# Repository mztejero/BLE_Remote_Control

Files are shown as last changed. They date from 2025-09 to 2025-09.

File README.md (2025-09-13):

<p align="center">
Plot
</p>

This remote control is designed to send incremental inputs over Bluetooth Low Energy. In this specific application, steering and throttle values are set with the rotary encoders and the x and y values of the joysticks are set in a range of -100 to 100. All of these values are sent as a package over BLE.
Running the ```ble_test.py``` shows the unpacked messages being received as shown below. 

<p align="center">
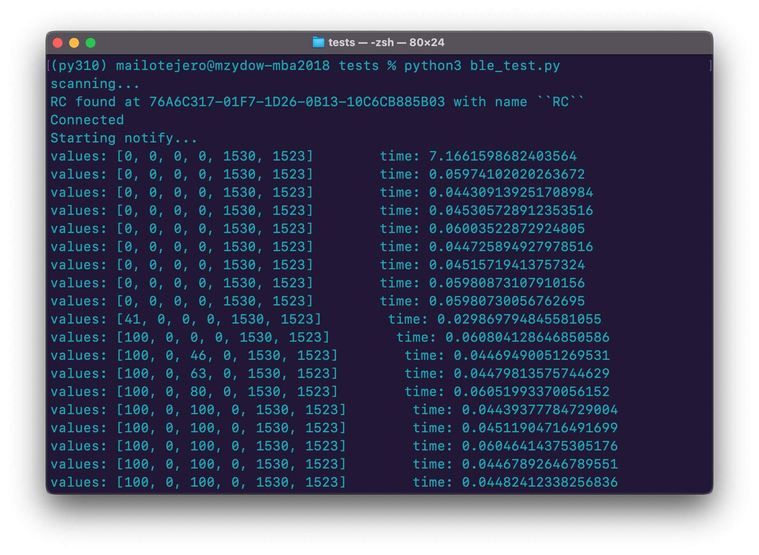
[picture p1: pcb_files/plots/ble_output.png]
Plot

</p>

# ESP-IDF
The file architecture is split into each of the remote's functions with each ```.c``` file also havng a complementary ```.h``` file allowing variable and function sharng across the project.
The files can be found in ```BLE_Remote_Control/main```:
```
config.c
joystick.c
bluetooth.c
encoder.c
lcd.c
buttons.c
main.c
```
```config.c```      Sets up and names the GPIO's used on the ESP32. <br>
```joystick.c```    Reads ADC values from the joystick potentiometers, estimates offsets, and converts the values into a range from -100 to 100. <br>
```bluetooth.c```  Uses NimBLE to run the ESP32 as a server by advertising through a GAP and publishing data packets through a GATT at 50 Hz. <br>
```encoder.c```     Sets up interrupts on quadrature encoders A and B terminals with tasks for counting which are added to queues. <br>
```lcd.c ```        Handles communication with LCD 16x02 via I<sup>2</sup>C. Transfers data through 4-bit nibbles and prints values on the screen (as shown in first picture). <br>
```buttons.c```     Placeholder script for reading switch values from encoders and joysticks. These are not currently used in this project. <br>
```main.c```        Main script for initializing and running the project on ESP32.

# Schematics
<p align="center">
<img src="pcb_files/plots/RC_schematics.png" alt="Plot" width="700"/>
</p>

This PCB is designed using the following components:

## SMD Components
ESP32-WROOM-32E -- Microcontroller used to run firmware, read sensors, write to actuators, and handle BLE communication. <br>
CP2102A USB-to-UART -- Interface for uploading code to the ESP32-WROOM-32E. The NPN transistors circuitry automatically put the ESP32 into bootloader mode when a new upload happens.<br>
<br>
PCF8574A I2C I/O for LCD communication -- Uses SCL and SDA to convert I<sup>2</sup>C data into bits to send to the LCD 16x02. Circuitry implements n-type MOSFETs for level shifting between 5V and 3V3 <br>
AMS1117-3.3 -- Converts 5V into 3.3V for components requiring 3V3<br>

## Hand-Soldered Components
Rotary Encoders -- Quadrature encoders with A and B terminals connected to GPIOs with pull-ups. Interrupts on these pull-ups are triggered upon rotation. <br>
Joysticks -- Use 2 potentiometers, one for x direction and one for y direction. These values are read through the ESP32's ADC. <br>
LCD 16x02 -- Displays characters on a 16×2 grid from data bits. <br>
Potentiometer -- Adjusts LCD lighting. <br>

# Final PCB Design
<p align="center">
<img src="pcb_files/plots/RC_pcb.png" alt="Plot" width="700"/>
</p>

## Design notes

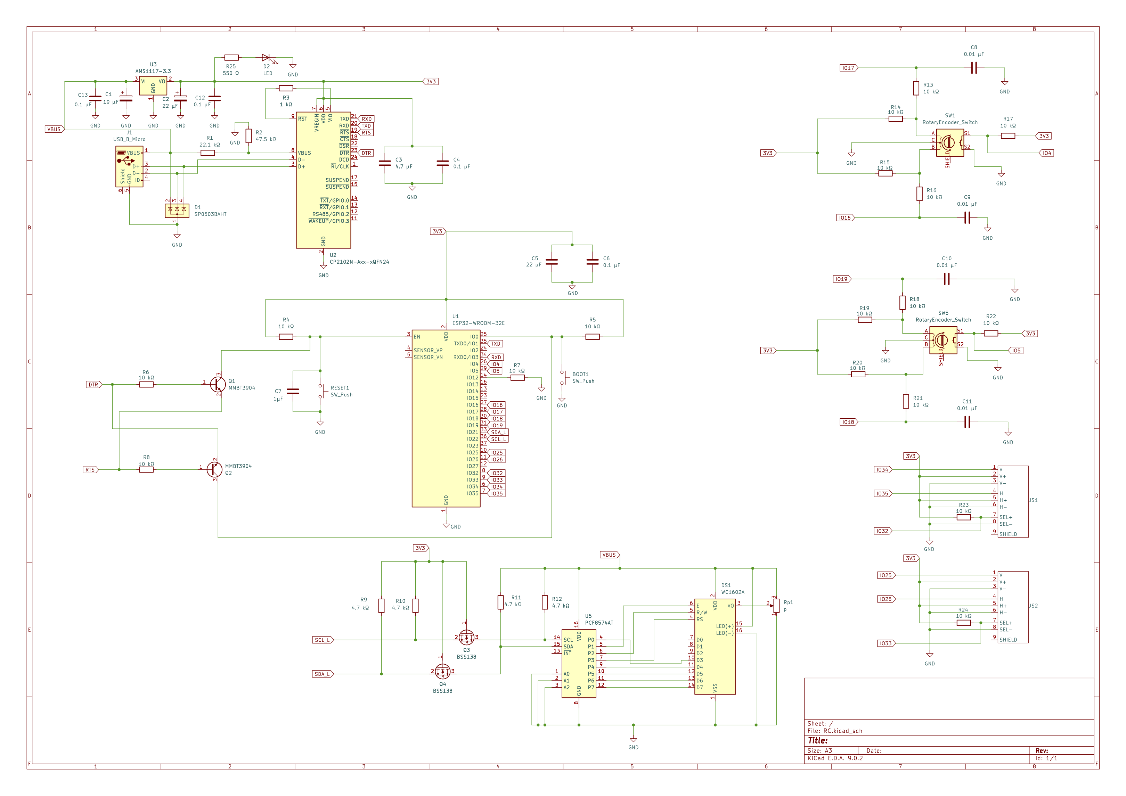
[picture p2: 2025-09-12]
pcb_files/plots/RC_schematics.png

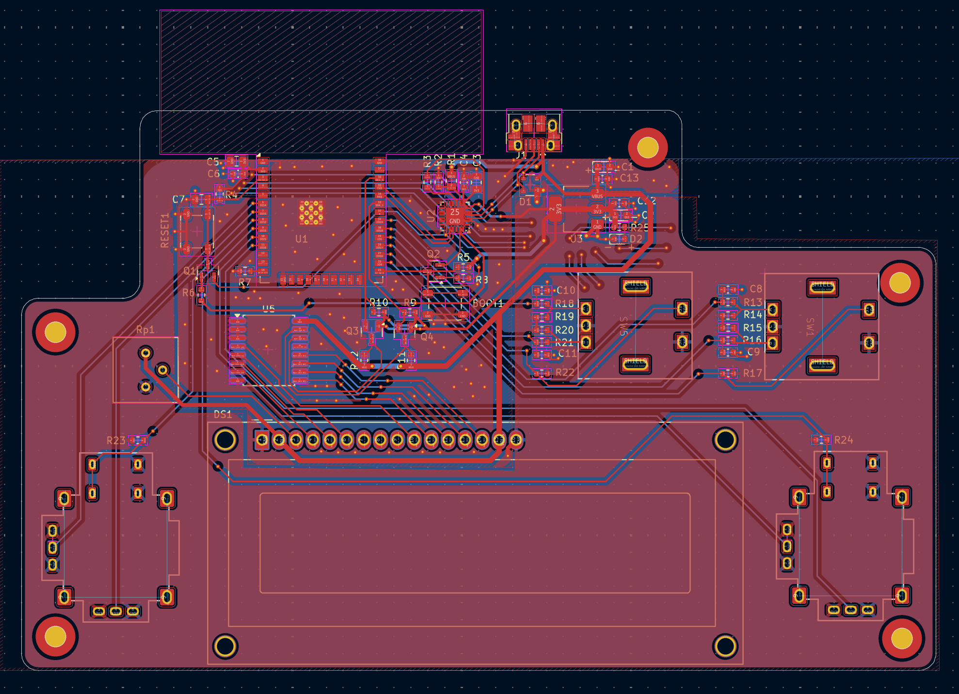
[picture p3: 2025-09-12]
pcb_files/plots/RC_pcb.png

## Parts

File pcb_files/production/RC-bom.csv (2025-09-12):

Comment | Designator | LCSC | MFR.Part # | Footprint
SW_Push | BOOT1,RESET1 | C2689502 | PTS647SM38SMTR2LFS | Button_Switch_SMD:SW_SPST_PTS647_Sx38
10 uF | C1 | C313067 | TLJR106M010R2000 | Capacitor_Tantalum_SMD:CP_EIA-2012-12_Kemet-R
22 uF | C2 | C11383 | TAJR106M006RNJ | Capacitor_Tantalum_SMD:CP_EIA-2012-12_Kemet-R
4.7 uF | C3 | C1779 | CL21A475KAQNNNE | Capacitor_SMD:C_0805_2012Metric
0.1 uF | C4,C6,C12,C13 | C14663 | CC0603KRX7R9BB104 | Capacitor_SMD:C_0603_1608Metric
22 uF | C5 | C45783 | CL21A226MAQNNNE | Capacitor_SMD:C_0805_2012Metric
1 uF | C7 | C28323 | CL21B105KBFNNNE | Capacitor_SMD:C_0805_2012Metric
0.01 uF | C8,C9,C10,C11 | C57112 | 0603B103K500NT | Capacitor_SMD:C_0603_1608Metric
SP0503BAHT | D1 | C7074 | SP0503BAHTG | Package_TO_SOT_SMD:SOT-143
LED | D2 | C2286 | KT-0603R | LED_SMD:LED_0603_1608Metric
Micr USB | J1 | C428495 | 10103594-0001LF | Connector_USB:USB_Micro-B_Amphenol_10103594-0001LF_Horizontal
NPN | Q1,Q2 | C20526 | MMBT3904 | Package_TO_SOT_SMD:SOT-23
MOSFET-n | Q3,Q4 | C78284 | BSS138 | Package_TO_SOT_SMD:SOT-23
22.1 k ohm | R1 | C325880 | RMC080522.1K1%N | Resistor_SMD:R_0805_2012Metric
47.5 k ohm | R2 | C23061 | 0603WAF4752T5E | Resistor_SMD:R_0603_1608Metric
1 k ohm | R3 | C21190 | 0603WAF1001T5E | Resistor_SMD:R_0603_1608Metric
10 k ohm | R4,R5,R6,R7,R8,R13,R14,R15,R16,R17,R18,R19,R20,R21,R22,R23,R24 | C25804 | 0603WAF1002T5E | Resistor_SMD:R_0603_1608Metric
4.7 k ohm | R9,R10,R11,R12 | C25999 | 0603WAJ0472T5E | Resistor_SMD:R_0603_1608Metric
560 ohm | R25 | C23204 | 0603WAF5600T5E | Resistor_SMD:R_0603_1608Metric
ESP32-WROOM-32E | U1 | C701342 | ESP32-WROOM-32E-N8 | RF_Module:ESP32-WROOM-32E
CP2102N | U2 | C969151 | CP2102N-A02-GQFN24R | Package_DFN_QFN:QFN-24-1EP_4x4mm_P0.5mm_EP2.6x2.6mm
AMS1117-3.3 | U3 | C6186 | AMS1117-3.3 | Package_TO_SOT_SMD:SOT-223-3_TabPin2
PCF8574AT | U5 | C86832 | PCF8574AT/3,518 | Package_SO:SOIC-16W_7.5x10.3mm_P1.27mm

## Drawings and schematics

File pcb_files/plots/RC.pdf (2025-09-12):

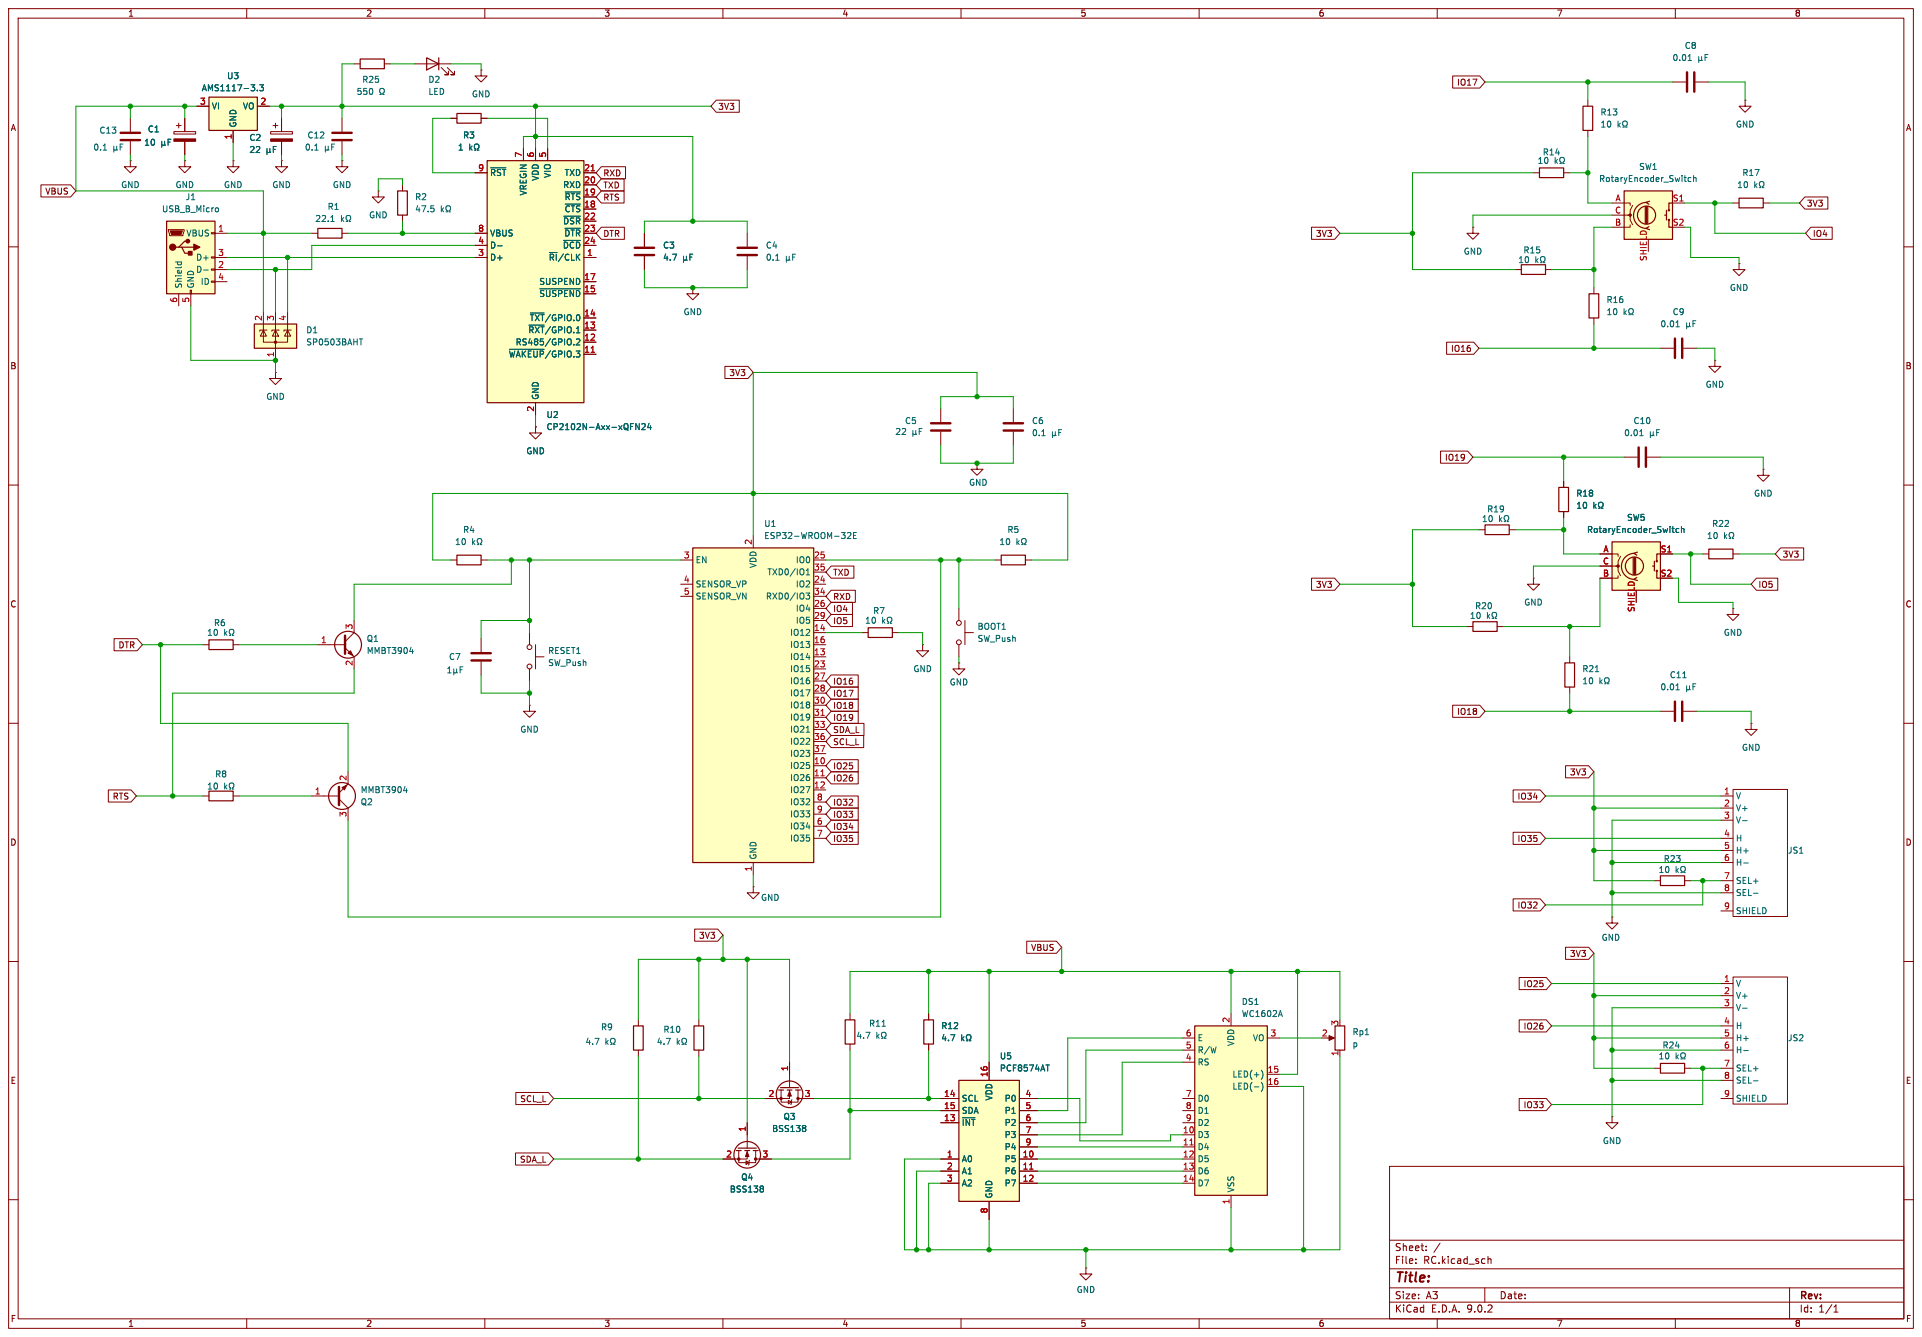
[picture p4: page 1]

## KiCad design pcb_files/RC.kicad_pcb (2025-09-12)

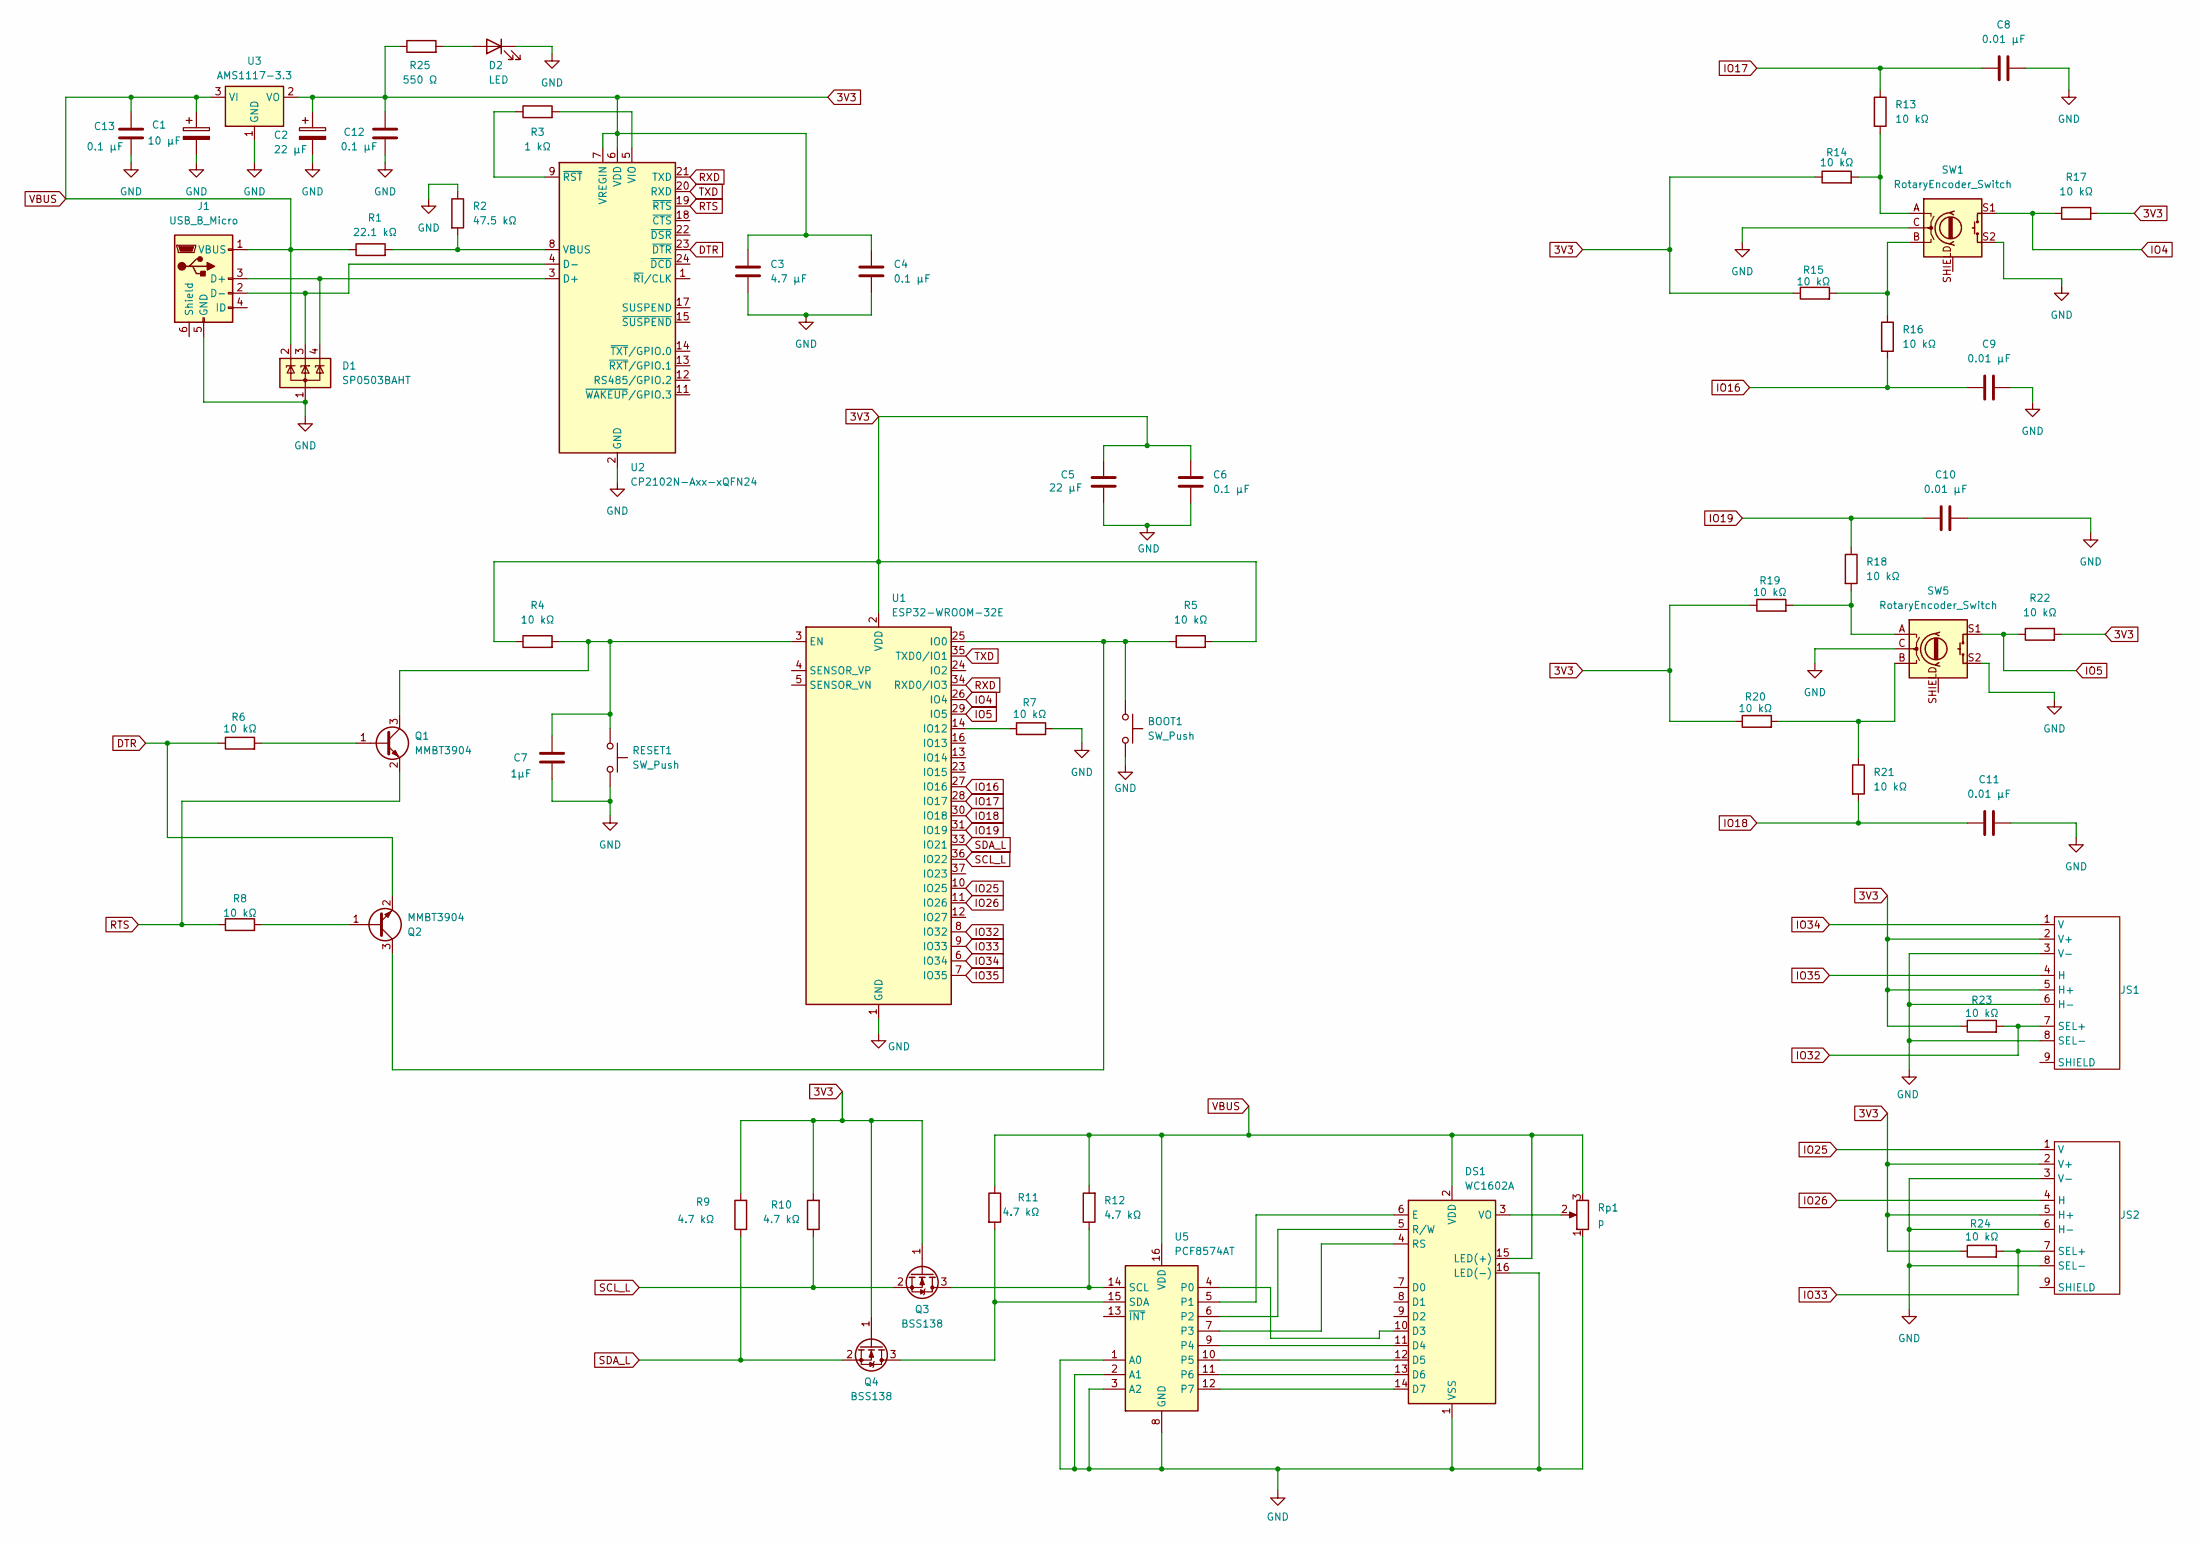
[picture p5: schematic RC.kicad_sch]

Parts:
BOOT1: SW_Push; SW_SPST_PTS647_Sx38
C1: 10 µF; CP_EIA-2012-12_Kemet-R
C2: 22 µF; CP_EIA-2012-12_Kemet-R
C3: 4.7 µF; C_0805_2012Metric
C4, C6, C12, C13: 0.1 µF; C_0603_1608Metric
C5: 22 µF; C_0805_2012Metric
C7: 1µF; C_0805_2012Metric
C8, C9, C10, C11: 0.01 µF; C_0603_1608Metric
D1: SP0503BAHT; SOT-143
D2: LED; LED_0603_1608Metric
DS1: WC1602A
J1: USB_B_Micro; USB_Micro-B_Amphenol_10103594-0001LF_Horizontal
JS1, JS2: Joystick
Q1, Q2: MMBT3904; SOT-23
Q3, Q4: BSS138; SOT-23
R1: 22.1 kΩ; R_0805_2012Metric
R2: 47.5 kΩ; R_0603_1608Metric
R3: 1 kΩ; R_0603_1608Metric
R4, R5, R6, R7, R8, R13, R14, R15, R16, R17, R18, R19, R20, R21, R22, R23, R24: 10 kΩ; R_0603_1608Metric
R9, R10, R11, R12: 4.7 kΩ; R_0603_1608Metric
R25: 550 Ω; R_0603_1608Metric
RESET1: SW_Push; SW_SPST_PTS647_Sx38
Rp1: p; Potentiometer_Bourns_3386P_Vertical
SW1, SW5: RotaryEncoder_Switch; Rotary_Encoder_RC
U1: ESP32-WROOM-32E
U2: CP2102N-Axx-xQFN24; QFN-24-1EP_4x4mm_P0.5mm_EP2.6x2.6mm
U3: AMS1117-3.3; SOT-223-3_TabPin2
U5: PCF8574AT; SOIC-16W_7.5x10.3mm_P1.27mm

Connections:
3V3: C2.1, C3.1, C4.1, C5.1, C6.1, C12.1, JS1.2 (V+), JS1.5 (H+), JS2.2 (V+), JS2.5 (H+), Q3.1 (G), Q4.1 (G), R4.1, R5.2, R9.2, R10.2, R14.1, R15.1, R17.2, R19.1, R20.1, R22.2, R23.1, R24.1, R25.1, U1.2 (VDD), U2.6 (VDD), U2.7 (VREGIN), U3.2 (VO)
DTR: Q2.2 (E), R6.1, U2.23 (~DTR)
GND: BOOT1.2, C1.2, C2.2, C3.2, C4.2, C5.2, C6.2, C7.2, C8.2, C9.2, C10.2, C11.2, C12.2, C13.2, D1.1 (A), D2.1 (K), DS1.1 (VSS), DS1.16 (LED(-)), J1.5 (GND), JS1.3 (V-), JS1.6 (H-), JS1.8 (SEL-), JS2.3 (V-), JS2.6 (H-), JS2.8 (SEL-), R2.1, R7.2, RESET1.2, Rp1.1, SW1.C, SW1.S2, SW5.C, SW5.S2, U1.1 (GND), U1.15 (GND), U1.38 (GND), U1.39 (GND), U2.2 (GND), U2.25 (GND), U3.1 (GND), U5.1 (A0), U5.2 (A1), U5.3 (A2), U5.8 (GND)
IO4: R17.1, SW1.S1, U1.26 (IO4)
IO5: R22.1, SW5.S1, U1.29 (IO5)
IO16: C9.1, R16.2, U1.27 (IO16)
IO17: C8.1, R13.1, U1.28 (IO17)
IO18: C11.1, R21.2, U1.30 (IO18)
IO19: C10.1, R18.1, U1.31 (IO19)
IO25: JS2.1 (V), U1.10 (IO25)
IO26: JS2.4 (H), U1.11 (IO26)
IO32: JS1.7 (SEL+), R23.2, U1.8 (IO32)
IO33: JS2.7 (SEL+), R24.2, U1.9 (IO33)
IO34: JS1.1 (V), U1.6 (IO34)
IO35: JS1.4 (H), U1.7 (IO35)
unnamed: D2.2 (A), R25.2
unnamed: DS1.10 (D3), U5.4 (P0)
unnamed: DS1.11 (D4), U5.9 (P4)
unnamed: DS1.12 (D5), U5.10 (P5)
unnamed: DS1.13 (D6), U5.11 (P6)
unnamed: DS1.14 (D7), U5.12 (P7)
unnamed: DS1.6 (E), U5.5 (P1)
unnamed: DS1.4 (RS), U5.7 (P3)
unnamed: DS1.5 (R/W), U5.6 (P2)
unnamed: DS1.3 (VO), Rp1.2
unnamed: D1.4 (K), J1.3 (D+), U2.3 (D+)
unnamed: D1.3 (K), J1.2 (D-), U2.4 (D-)
unnamed: Q1.1 (B), R6.2
unnamed: C7.1, Q1.3 (C), R4.2, RESET1.1, U1.3 (EN)
unnamed: Q2.1 (B), R8.2
unnamed: BOOT1.1, Q2.3 (C), R5.1, U1.25 (IO0)
unnamed: Q3.3 (D), R12.1, U5.14 (SCL)
unnamed: Q4.3 (D), R11.2, U5.15 (SDA)
unnamed: R13.2, R14.2, SW1.A
unnamed: R15.2, R16.1, SW1.B
unnamed: R18.2, R19.2, SW5.A
unnamed: R20.2, R21.1, SW5.B
unnamed: R7.1, U1.14 (IO12)
unnamed: R1.2, R2.2, U2.8 (VBUS)
unnamed: R3.2, U2.5 (VIO)
unnamed: R3.1, U2.9 (~RST)
RTS: Q1.2 (E), R8.1, U2.19 (~RTS)
RXD: U1.34 (RXD0/IO3), U2.21 (TXD)
SCL_L: Q3.2 (S), R10.1, U1.36 (IO22)
SDA_L: Q4.2 (S), R9.1, U1.33 (IO21)
TXD: U1.35 (TXD0/IO1), U2.20 (RXD)
VBUS: C1.1, C13.1, D1.2 (K), DS1.2 (VDD), DS1.15 (LED(+)), J1.1 (VBUS), R1.1, R11.1, R12.2, Rp1.3, U3.3 (VI), U5.16 (VDD)

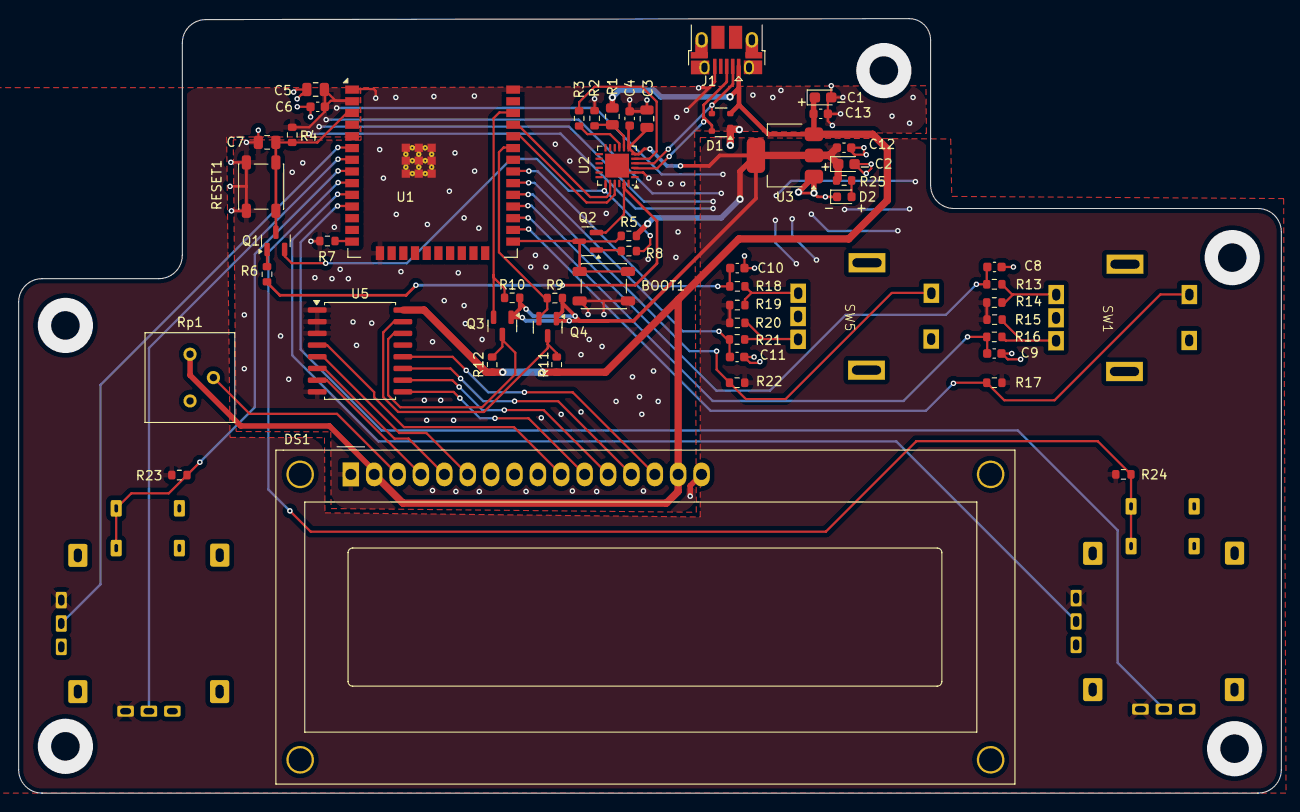
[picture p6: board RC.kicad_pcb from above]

Board: 2 copper layers, 137.2 x 84.1 mm, 57 parts (0 on the bottom side), 47 nets.

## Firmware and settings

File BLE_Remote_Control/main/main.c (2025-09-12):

// idf.py -p /dev/cu.usbserial-1410 -b 115200 flash monitor
#include "config.h"
#include "encoder.h"
#include "joystick.h"
#include "buttons.h"
#include "bluetooth.h"
#include "lcd.h"

void app_main(void) {
    enc_table();
    setup_gpio();
    setup_adc();
    setup_queues();
    setup_isr();
    initialize_joystick(&js_l, &js_r, &params);
    ble_main_init();
    setup_i2c();
    lcd_init();
    lcd_clear();
    lcd_task();
    while (1) {
        read_joystick(&js_l, &js_r, &params);
        printf("JS vxl: %d, vyl: %d, vxr: %d, vyr: %d | Enc L: %d, R: %d\n",
               js.vxl, js.vyl, js.vxr, js.vyr, count_l/4, count_r/4);
        vTaskDelay(pdMS_TO_TICKS(50));
    }
}

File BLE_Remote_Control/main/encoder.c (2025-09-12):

#include "config.h"

#include <stdio.h>
#include "freertos/FreeRTOS.h"
#include "freertos/task.h"

// Global Variables
volatile int count_l = 1500 * 4;
volatile int count_r = 1500 * 4;

// Define Handles
QueueHandle_t queue_l;
QueueHandle_t queue_r;

// Encoder Lookup Table
int8_t enc[256] = {0};
void enc_table(void) {
    enc[0b0001] = -1;
    enc[0b0111] = -1;
    enc[0b1110] = -1;
    enc[0b1000] = -1;

    enc[0b0010] = 1;
    enc[0b0100] = 1;
    enc[0b1101] = 1;
    enc[0b1011] = 1;
}

// ISR's
void IRAM_ATTR left_isr_handler(void *arg) {
    static uint8_t state_l = 0b1111;

    uint8_t clk = gpio_get_level(pins.clk_l);
    uint8_t dt = gpio_get_level(pins.dt_l);

    uint8_t curr = (clk << 1) | dt;
    state_l = (state_l << 2) | curr;
    uint8_t state = state_l;

    BaseType_t xHPW = pdFALSE;
    xQueueSendFromISR(queue_l, &state, (TickType_t)0);
    if (xHPW) portYIELD_FROM_ISR();
}

void IRAM_ATTR right_isr_handler(void *arg) {
    static uint8_t state_r = 0b1111;

    uint8_t clk = gpio_get_level(pins.clk_r);
    uint8_t dt = gpio_get_level(pins.dt_r);
    
    uint8_t curr = (clk << 1) | dt;
    state_r = (state_r << 2) | curr;
    uint8_t state = state_r;

    BaseType_t xHPW = pdFALSE;
    xQueueSendFromISR(queue_r, &state, (TickType_t)0);
    if (xHPW) portYIELD_FROM_ISR(); 
}

static inline void print_u8_bin(uint8_t v)
{
    for (int i = 7; i >= 0; --i) {
        putchar((v & (1 << i)) ? '1' : '0');
    }
}

void left_isr_task(void *arg) {
    uint8_t state;
    while (1) {
        if (xQueueReceive(queue_l, &state, portMAX_DELAY) == pdTRUE) {
            count_l += enc[state & 0x0F];
        }
    }
}

void right_isr_task(void *arg) {
    uint8_t state;
    while (1) {
        if (xQueueReceive(queue_r, &state, portMAX_DELAY) == pdTRUE) {
            count_r += enc[state & 0x0F];
        }
    }
}

// Queue Setup
void setup_queues(void) {
    queue_l = xQueueCreate(64, sizeof(uint8_t));
    queue_r = xQueueCreate(64, sizeof(uint8_t));
    if (!queue_l || !queue_r) {
        printf("Failed to create queues\n");
    }

    if (xTaskCreate(left_isr_task, "left_isr_task", 2048, NULL, 10, NULL) != pdPASS) {
        printf("Failed to create left_isr_task\n");
    }
    if (xTaskCreate(right_isr_task, "right_isr_task", 2048, NULL, 10, NULL) != pdPASS) {
        printf("Failed to create right_isr_task\n");
    }

}

// ISR Setup
void setup_isr(void) {
    gpio_install_isr_service(0);

    gpio_isr_handler_add(pins.clk_l, left_isr_handler, (void* )pins.clk_l);
    gpio_isr_handler_add(pins.dt_l, left_isr_handler, (void* )pins.dt_l);
    gpio_isr_handler_add(pins.clk_r, right_isr_handler, (void* )pins.clk_r);
    gpio_isr_handler_add(pins.dt_r, right_isr_handler, (void* )pins.dt_r);
}
